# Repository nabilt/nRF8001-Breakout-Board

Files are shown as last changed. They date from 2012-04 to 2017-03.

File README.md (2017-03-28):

nRF8001-Breakout-Board
==========================================

* Author:    Nabil Tewolde (<nabil.tewolde@gmail.com>)
* Version:   0.9
* Website:   <http://www.nabiltewolde.com>
* GitHub:    <https://github.com/nabilt/nRF8001-Breakout-Board>

This hardware project is the reference schematic for the [nRF8001] Bluetooth Low Energy chip redone in Eagle. It is currently untested. The goal of this project is to develop a low power, cheap, cross-platform wireless module for wireless projects. I plan to include open firmware and demos for iOS and Android. Checkout my [blog post] for more info.

[nRF8001]: http://www.nordicsemi.com/eng/Products/Bluetooth-R-low-energy/nRF8001
[blog post]: https://nabil.me/2012/04/09/open-source-bluetooth-4-breakout-board-means-no-more-mi-fi/
Why nRF8001 and not another [Bluetooth 4 chip]?

* Publicly available datasheet
* Simple circuitry, few passives and no integrated uC
* Cheap, $4.98 CAD on [Mouser]
* Small, currently the board is 1’’ x 0.9’’

[Bluetooth 4 chip]: http://developer.bluetooth.org/DevelopmentResources/DevelopmentPlatforms/Pages/Development-Platforms.aspx
[Mouser]: http://ca.mouser.com/ProductDetail/Nordic-Semiconductor/nRF8001-R2Q32-T/?qs=yd0qOhnSiDfAxQAlSXMVEQ%3d%3d

Interesting Bluetooth 4 facts:

* Runs for years on a coin cell battery
* Works over a wide range; 10 to 100 meters
* 1Mbps over the air data rate; 0.2 Mbps throughput 
* Virtually all new devices made in 2012 will contain Bluetooth 4 
* Apple only provides a free API for Bluetooth 4 accessories

Checkout <http://www.bluetooth.com/Pages/Bluetooth-Smart-Devices.aspx> for a list of Bluetooth 4 compatible devices.

Licensing
---------

nRF8001-Breakout-Board by Nabil Tewolde is licensed under a Creative Commons Attribution-ShareAlike 3.0 Unported License.

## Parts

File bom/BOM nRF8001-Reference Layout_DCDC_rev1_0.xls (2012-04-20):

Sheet: Mouser BOM - Table 1
nRF8001 core circuitry Bill of Materials
DC/DC converter enabled
Designator | Value | Footprint | Manufacturer Part # | Mouser Part # | Mouser Price | Quantity | Item Total | Comment
C1, C2 | 18pF | 0603 | VJ0603A100GXACW1BC | 77-VJ0603A100GXACBC | 0.098 | 5 | 0.49 | NP0 +/- 2%
C13, C14 | 9pF | 0603 | GRM1885C1H9R0BZ01D | 81-GRM1885C1H9R0BZ01 | 0.098 | 5 | 0.49 | NP0 +/- 2%
C3 | 2.2nF | 0603 | 77-VJ0603A222GXJPBC | VJ0603A222GXJPW1BC | 0.142 | 3 | 0.426 | X7R +/- 10%
C4 | Not mounted | 0603 |  |  |  | 3 | 0
C5 | 1.8pF | 0603 | VJ0603A1R8BXXCW1BC | 77-VJ0603A1R8BXXCBC | 0.087 | 3 | 0.261 | NP0 +/-0.1pF
C6 | 1.2pF | 0603 | VJ0603A1R2BXACW1BC | 77-VJ0603A1R2BXACBC | 0.087 | 3 | 0.261 | NP0 +/-0.1pF
C7, C9 | 1.0µF | 0603 | C1608X7R1C105KT | 810-C1608X7R1C105K | 0.076 | 5 | 0.38 | X7R +/- 10%
C8 | 1.0nF | 0603 | CC0603KRX7R9BB102 | 603-CC603KRX7R9BB102 | 0.098 | 3 | 0.294 | X7R +/- 10%
C10, C12 | 100nF | 0603 | 0603YC104KAT2A | 581-060316C104K | 0.044 | 5 | 0.22 | X7R +/- 10%
C11 | 33nF | 0603 | C0603C333K4RACTM | 80-C0603C333K4RACTM | 0.076 | 3 | 0.228 | X7R +/- 10%
L1 | 8.2nH | 0603 | CI160808-8N2J | 652-CI160808-8N2J | 0.055 | 3 | 0.165 | High frequency chip inductor +/-5%
L2 | 5.6nH | 0603 | 744761056C | 710-744761056C | 0.36 | 3 | 1.08 | High frequency chip inductor +/-5%
L3 | 3.9nH | 0603 | B82496C3399J | 871-B82496C3399J | 0.382 | 3 | 1.146 | High frequency chip inductor +/-5%
L4 | 10µH | 0603 | MLZ1608M100WT | 810-MLZ1608M100W | 0.087 | 3 | 0.261 | Chip inductor, IDC,min = 50mA, +/-20%
L5 | 15nH | 0603 | L0603C15NJRMST | 80-L0603C15NJRMST | 0.131 | 3 | 0.393 | High frequency chip inductor +/-10%
R1 | 22k | 0603 | AC0603FR-0722KL | 603-AC0603FR-0722KL | 0.022 | 3 | 0.066 | +/-1%
U1 | nRF8001 | QFN32 | nRF8001-R2Q32-T | 949-NRF8001-R2Q32-T | 4.98 | 2 | 9.96 | QFN32 5x5 mm package
X1 | U1 | 3.2 x 2.5 mm | ABM8G-16.000MHZ-B4Y-T | 815-ABM8G-16-B4Y-T | 1.27 | 2 | 2.54 | SMD-3225, 16 MHz, CL=18pF, +/-30 ppm
X2 | 32.768kHz | 3.2 x 1.5 mm | ABS10-32.768KHZ-9-T | 815-ABS10-32.768K9T | 1.08 | 2 | 2.16 | 32.768kHz, Cl=9pF, ±20ppm
 | 2.4GHz |  | A24-HASM-450 | 888-A24-HASM-450 | 6.55 | 1 | 6.55 | Antenna
 |  |  |  |  |  |  | 0
Total |  |  |  |  | 9.173 |  | 27.371
Other Components
Designator | Value | Footprint | Manufacturer Part # |  | Price | Quantity | Item Total | Comment
PCB substrate | FR4 laminate | 18.4 x 16.7 mm |  |  | 1 | 10 | 10 | 2 layer, thickness 1.6 mm, from SeeedStudio
RP SMA |  |  |  |  | 1.95 | 2 | 3.9 | Sparkfun RP SMA
Total |  |  |  |  | 2.95 |  | 13.9
GRAND TOTAL | 41.271

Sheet: Mouser BOM Import - Table 1
C1, C2 | 77-VJ0603A100GXACBC | 10
C13, C14 | 81-GRM1885C1H9R0BZ01 | 10
C3 | VJ0603A222GXJPW1BC | 5
C4 |  | 5
C5 | 77-VJ0603A1R8BXXCBC | 5
C6 | 77-VJ0603A1R2BXACBC | 5
C7, C9 | 810-C1608X7R1C105K | 10
C8 | 603-CC603KRX7R9BB102 | 5
C10, C12 | 581-060316C104K | 10
C11 | 80-C0603C333K4RACTM | 5
L1 | 652-CI160808-8N2J | 5
L2 | 710-744761056C | 5
L3 | 871-B82496C3399J | 5
L4 | 810-MLZ1608M100W | 5
L5 | 80-L0603C15NJRMST | 5
R1 | 603-AC0603FR-0722KL | 5
U1 | 949-NRF8001-R2Q32-T | 2
X1 | 815-ABM8G-16-B4Y-T | 2
X2 | 815-ABS10-32.768K9T | 2

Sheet: Newark BOM - Table 1
nRF8001 core circuitry Bill of Materials
DC/DC converter enabled
Designator | Value | Footprint | Manufacturer Part # | Newark Part # | Newark Price | Comment
C1, C2 | 18pF | 0603 | VJ0603A100GXACW1BC |  |  | NP0 +/- 2%
C13, C14 | 9pF | 0603 | GRM1885C1H9R0BZ01D |  |  | NP0 +/- 2%
C3 | 2.2nF | 0603 | 77-VJ0603A222GXJPBC (http://ca.mouser.com/ProductDetail/Vishay-Vitramon/VJ0603A222GXJPW1BC/) |  |  | X7R +/- 10%
C4 | Not mounted | 0603
C5 | 1.8pF | 0603 | VJ0603A1R8BXXCW1BC |  |  | NP0 +/-0.1pF
C6 | 1.2pF | 0603 | VJ0603A1R2BXACW1BC |  |  | NP0 +/-0.1pF
C7, C9 | 1.0µF | 0603 | C1608X7R1C105KT |  |  | X7R +/- 10%
C8 | 1.0nF | 0603 | CC0603KRX7R9BB102 |  |  | X7R +/- 10%
C10, C12 | 100nF | 0603 | 0603YC104KAT2A |  |  | X7R +/- 10%
C11 | 33nF | 0603 | C0603C333K4RACTM |  |  | X7R +/- 10%
L1 | 8.2nH | 0603 | CI160808-8N2J |  |  | High frequency chip inductor +/-5%
L2 | 5.6nH | 0603 | 744761056C |  |  | High frequency chip inductor +/-5%
L3 | 3.9nH | 0603 | B82496C3399J |  |  | High frequency chip inductor +/-5%
L4 | 10µH | 0603 | MLZ1608M100WT |  |  | Chip inductor, IDC,min = 50mA, +/-20%
L5 | 15nH | 0603 | L0603C15NJRMST |  |  | High frequency chip inductor +/-10%
R1 | 22k | 0603 | AC0603FR-0722KL |  |  | +/-1%
 | nRF8001 | QFN32 | nRF8001-R2Q32-T |  |  | QFN32 5x5 mm package
X1 | U1 | 3.2 x 2.5 mm | ABM8G-16.000MHZ-B4Y-T |  |  | SMD-3225, 16 MHz, CL=18pF, +/-30 ppm
X2 | 32.768kHz | 3.2 x 1.5 mm | ABS10-32.768KHZ-9-T |  |  | 32.768kHz, Cl=9pF, ±20ppm
PCB substrate | FR4 laminate | 18.4 x 16.7 mm |  |  |  | 2 layer, thickness 1.6 mm
Total

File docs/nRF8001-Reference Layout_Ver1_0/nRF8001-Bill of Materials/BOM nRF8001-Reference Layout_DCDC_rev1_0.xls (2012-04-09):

Date: 2010-12-20
nRF8001 core circuitry Bill of Materials
DC/DC converter enabled
Designator | Value | Footprint | Comment
C1, C2, C13, C14 | 15pF | 0402 | NP0 +/- 2%
C3 | 2.2nF | 0402 | X7R +/- 10%
C4 | Not mounted | 0402
C5 | 1.8pF | 0402 | NP0 +/-0.1pF
C6 | 1.2pF | 0402 | NP0 +/-0.1pF
C7, C9 | 1.0µF | 0603 | X7R +/- 10%
C8 | 1.0nF | 0402 | X7R +/- 10%
C10, C12 | 100nF | 0402 | X7R +/- 10%
C11 | 33nF | 0402 | X7R +/- 10%
L1 | 8.2nH | 0402 | High frequency chip inductor +/-5%
L2 | 5.6nH | 0402 | High frequency chip inductor +/-5%
L3 | 3.9nH | 0402 | High frequency chip inductor +/-5%
L4 | 10µH | 0603 | Chip inductor, IDC,min = 50mA, +/-20%
L5 | 15nH | 0402 | High frequency chip inductor +/-10%
R1 | 22k | 0402 | +/-1%
U1 | nRF8001 | QFN32 | QFN32 5x5 mm package
X1 | 16MHz | 3.2 x 2.5 mm | SMD-3225, 16 MHz, CL=9pF, +/-50 ppm
X2 | 32.768kHz | 3.2 x 1.5 mm | SMD-3215, 32.768kHz, Cl=9pF, ±20ppm
PCB substrate | FR4 laminate | 18.4 x 16.7 mm | 2 layer, thickness 1.6 mm

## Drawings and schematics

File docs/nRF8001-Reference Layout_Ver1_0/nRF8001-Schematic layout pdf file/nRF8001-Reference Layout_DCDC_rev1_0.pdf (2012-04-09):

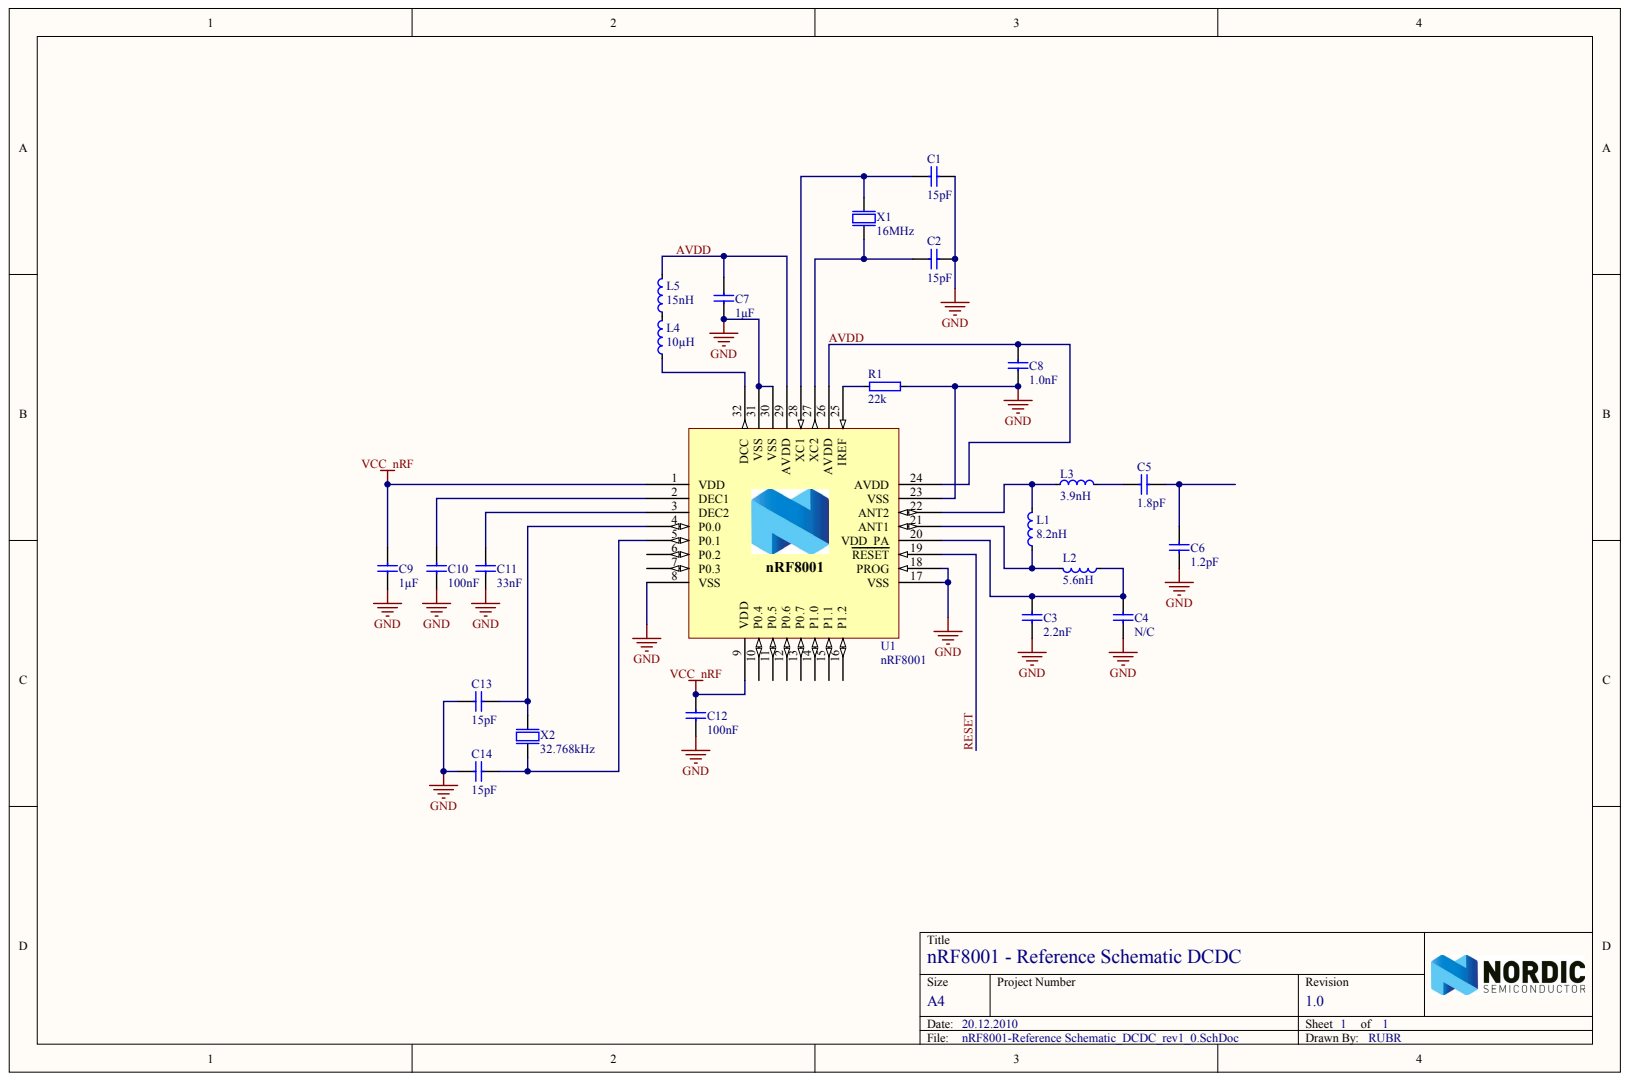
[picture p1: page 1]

Title Size nRF8001 - Reference Sche matic DCDC

A 4 | Project Number | Re visio n 1.0

Date: File: 20.12.201 0 | Sheet 1 o f 1

nRF8001-Reference Schematic_DCDC_rev 1_0.SchDoc | Drawn By : RUBR

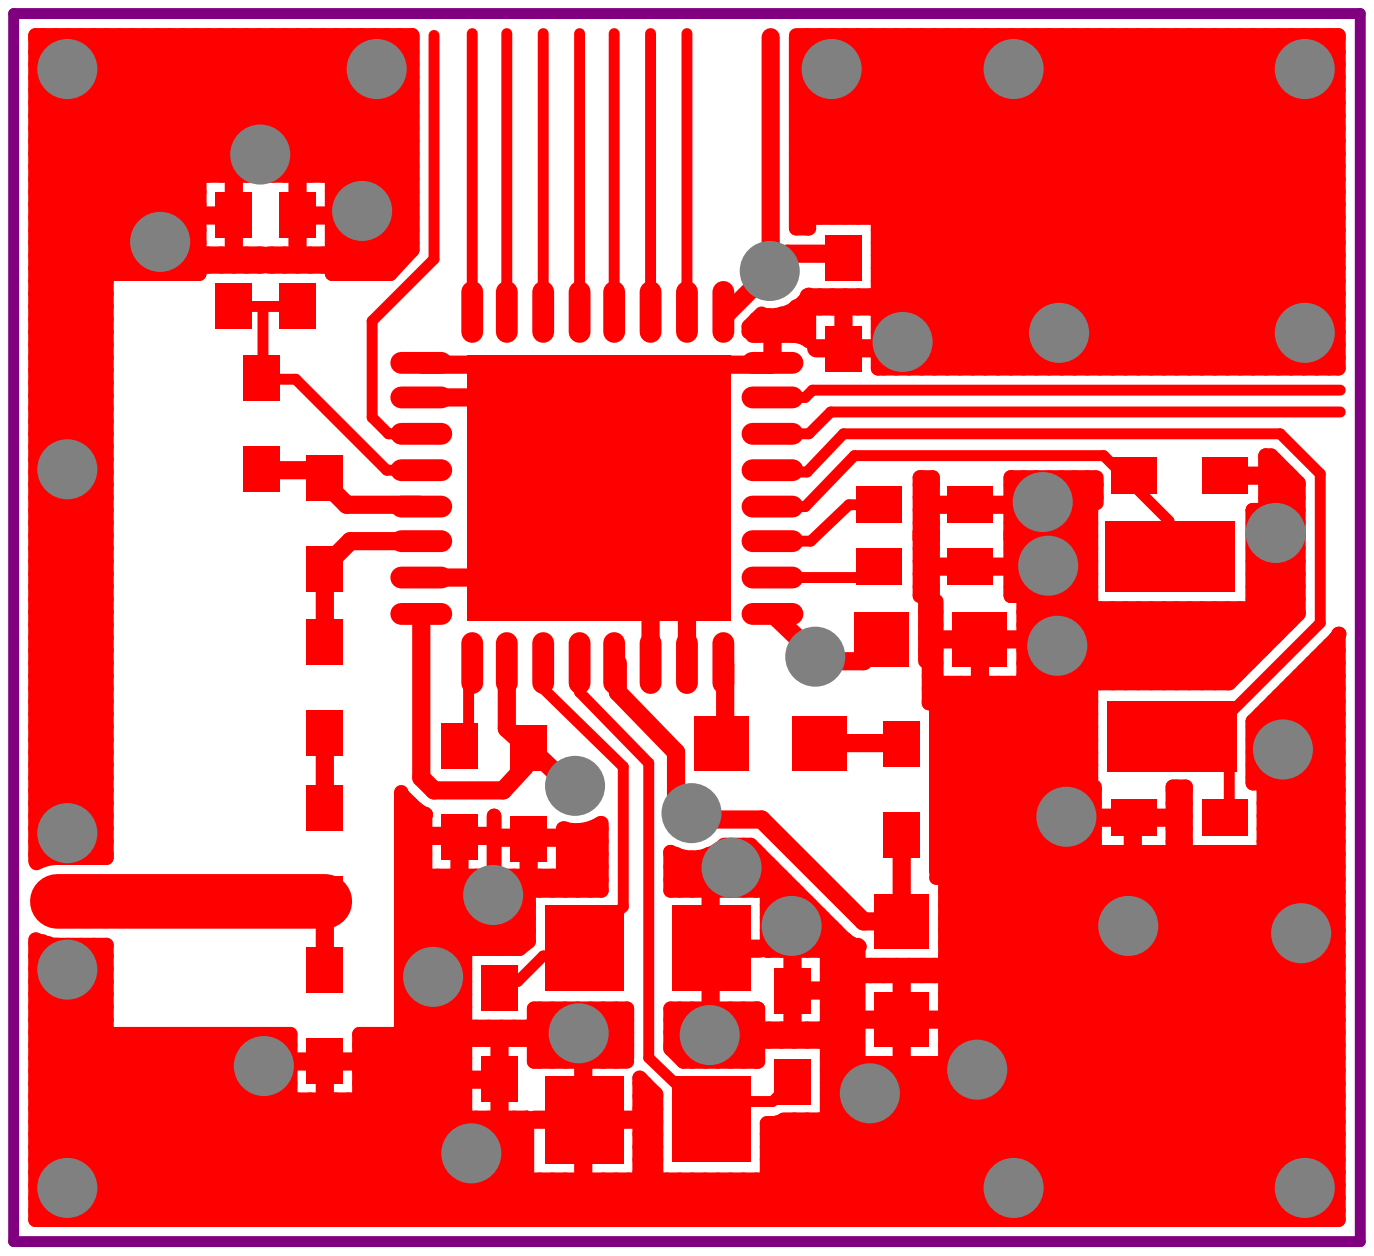
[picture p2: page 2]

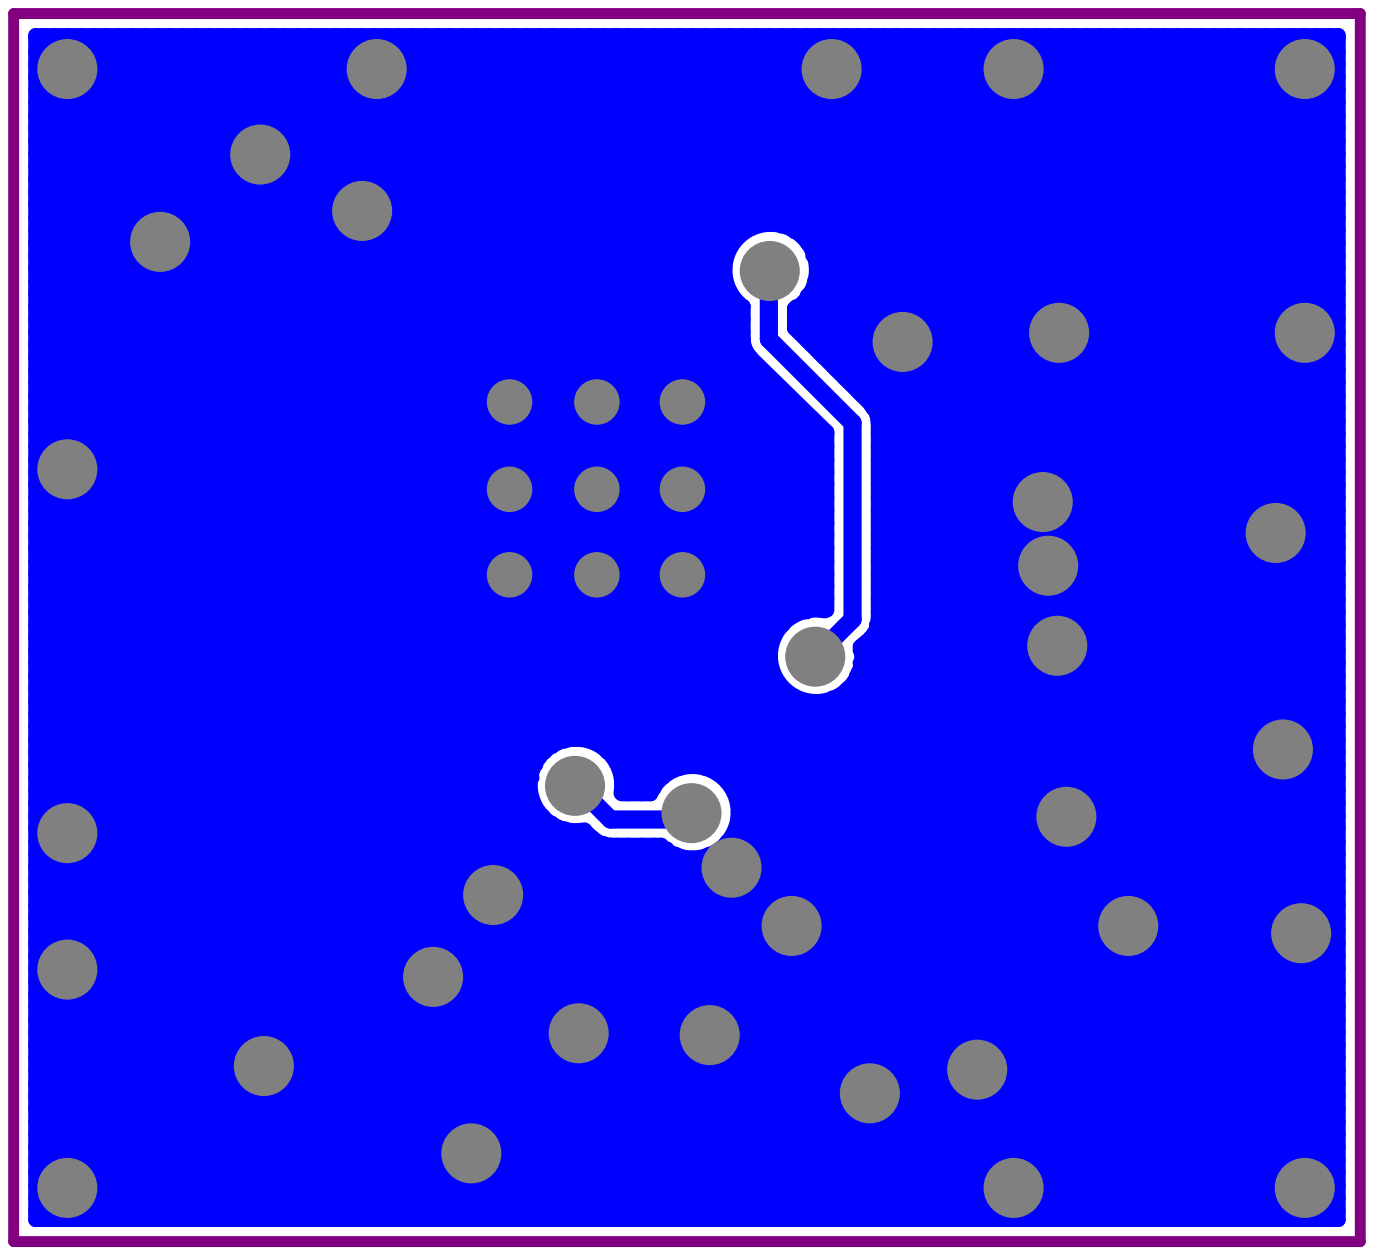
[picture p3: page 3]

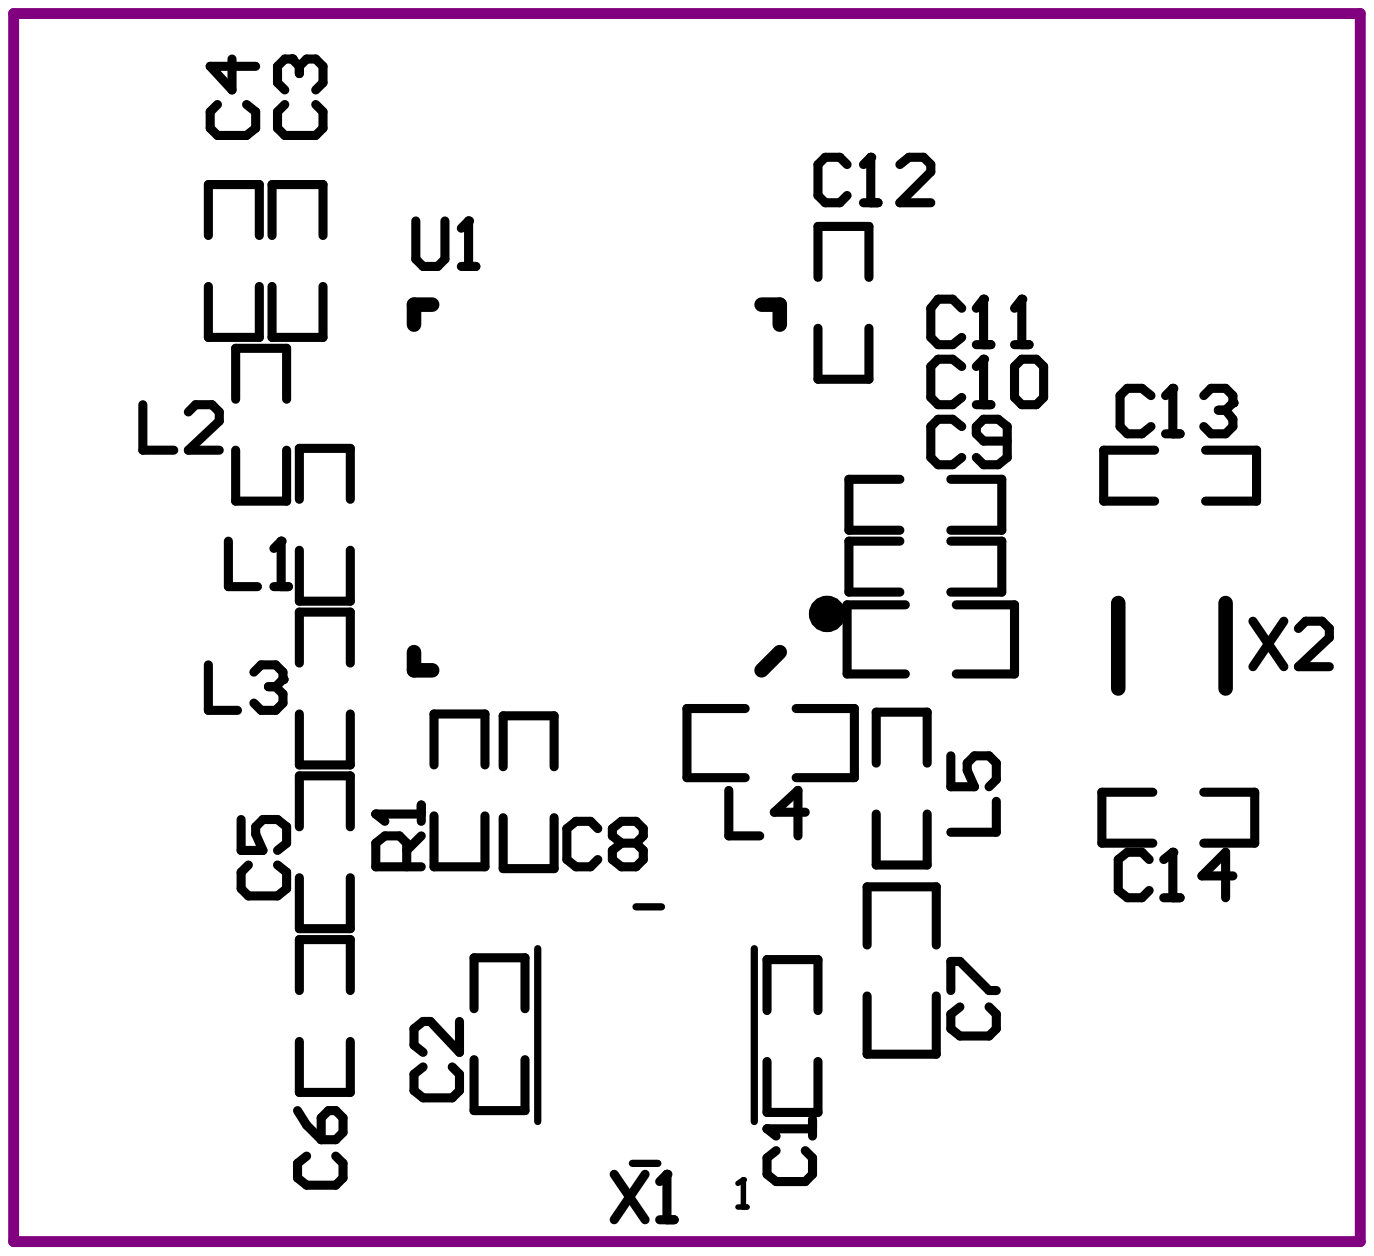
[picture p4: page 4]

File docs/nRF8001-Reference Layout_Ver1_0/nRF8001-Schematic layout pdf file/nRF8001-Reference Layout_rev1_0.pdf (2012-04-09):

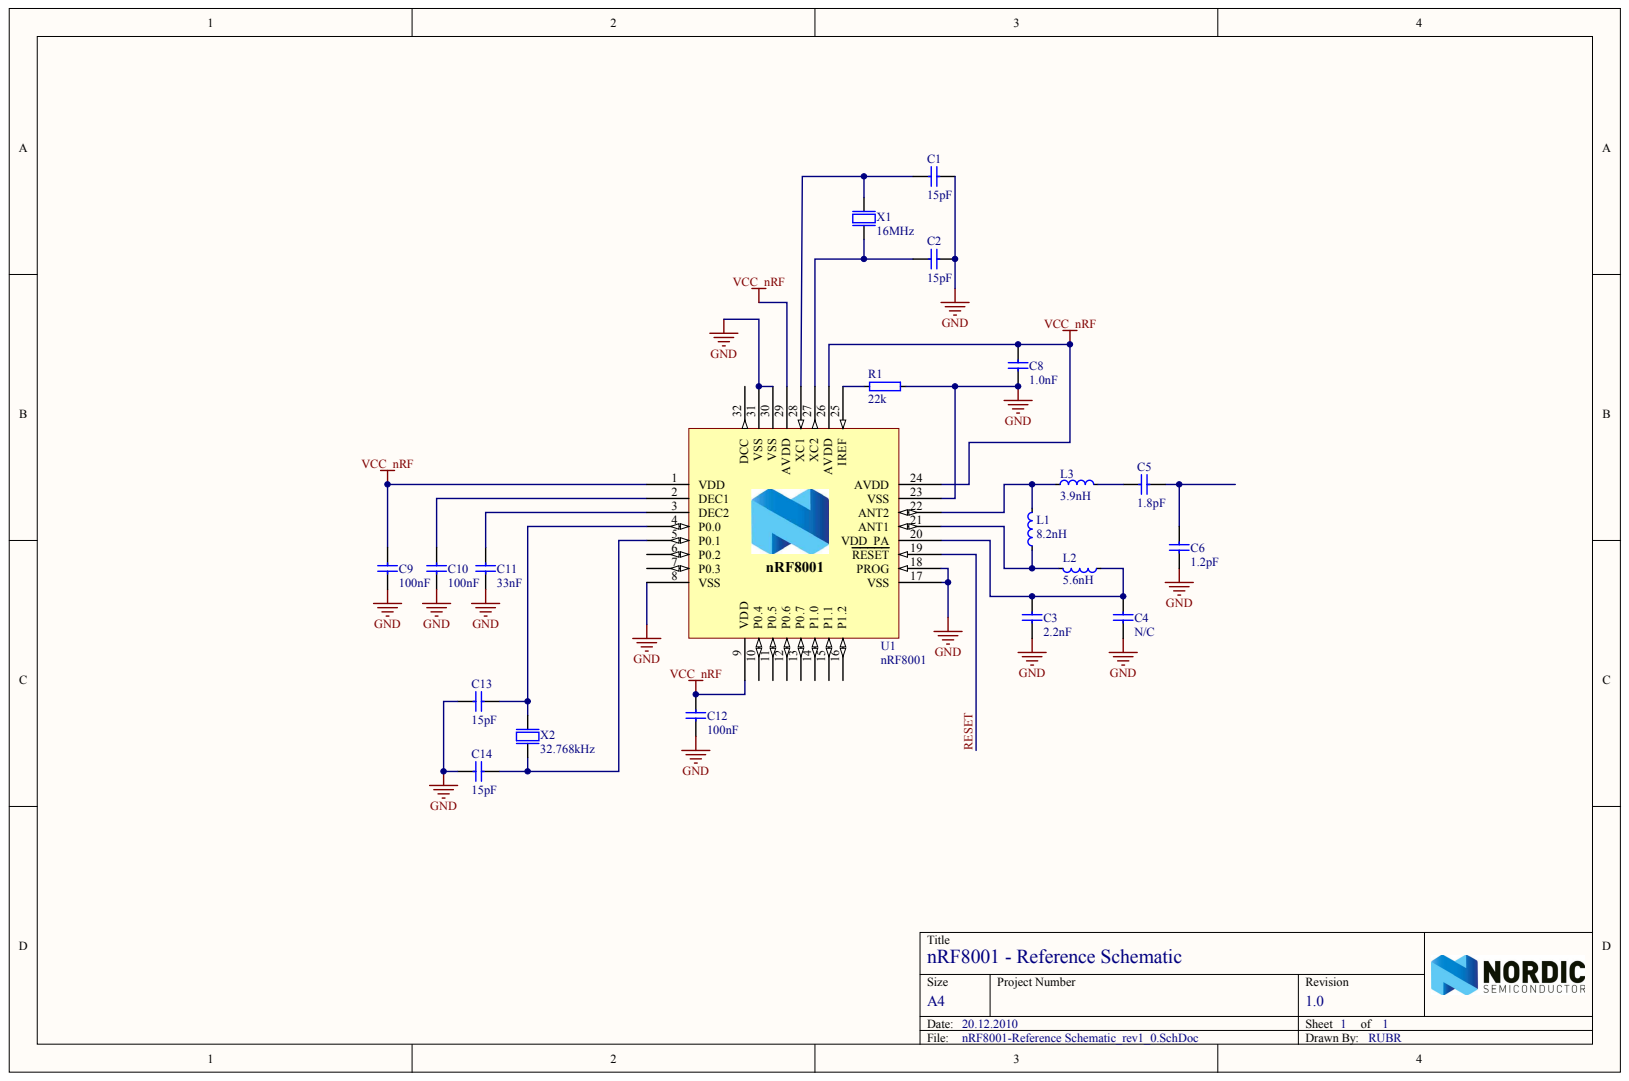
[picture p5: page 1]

Title Size nRF8001 - Reference Sche matic

A 4 | Project Number | Re visio n 1.0

Date: File: 20.12.201 0 | Sheet 1 o f 1

nRF8001-Reference Schematic_rev1_0.S chDoc | Drawn By : RUBR

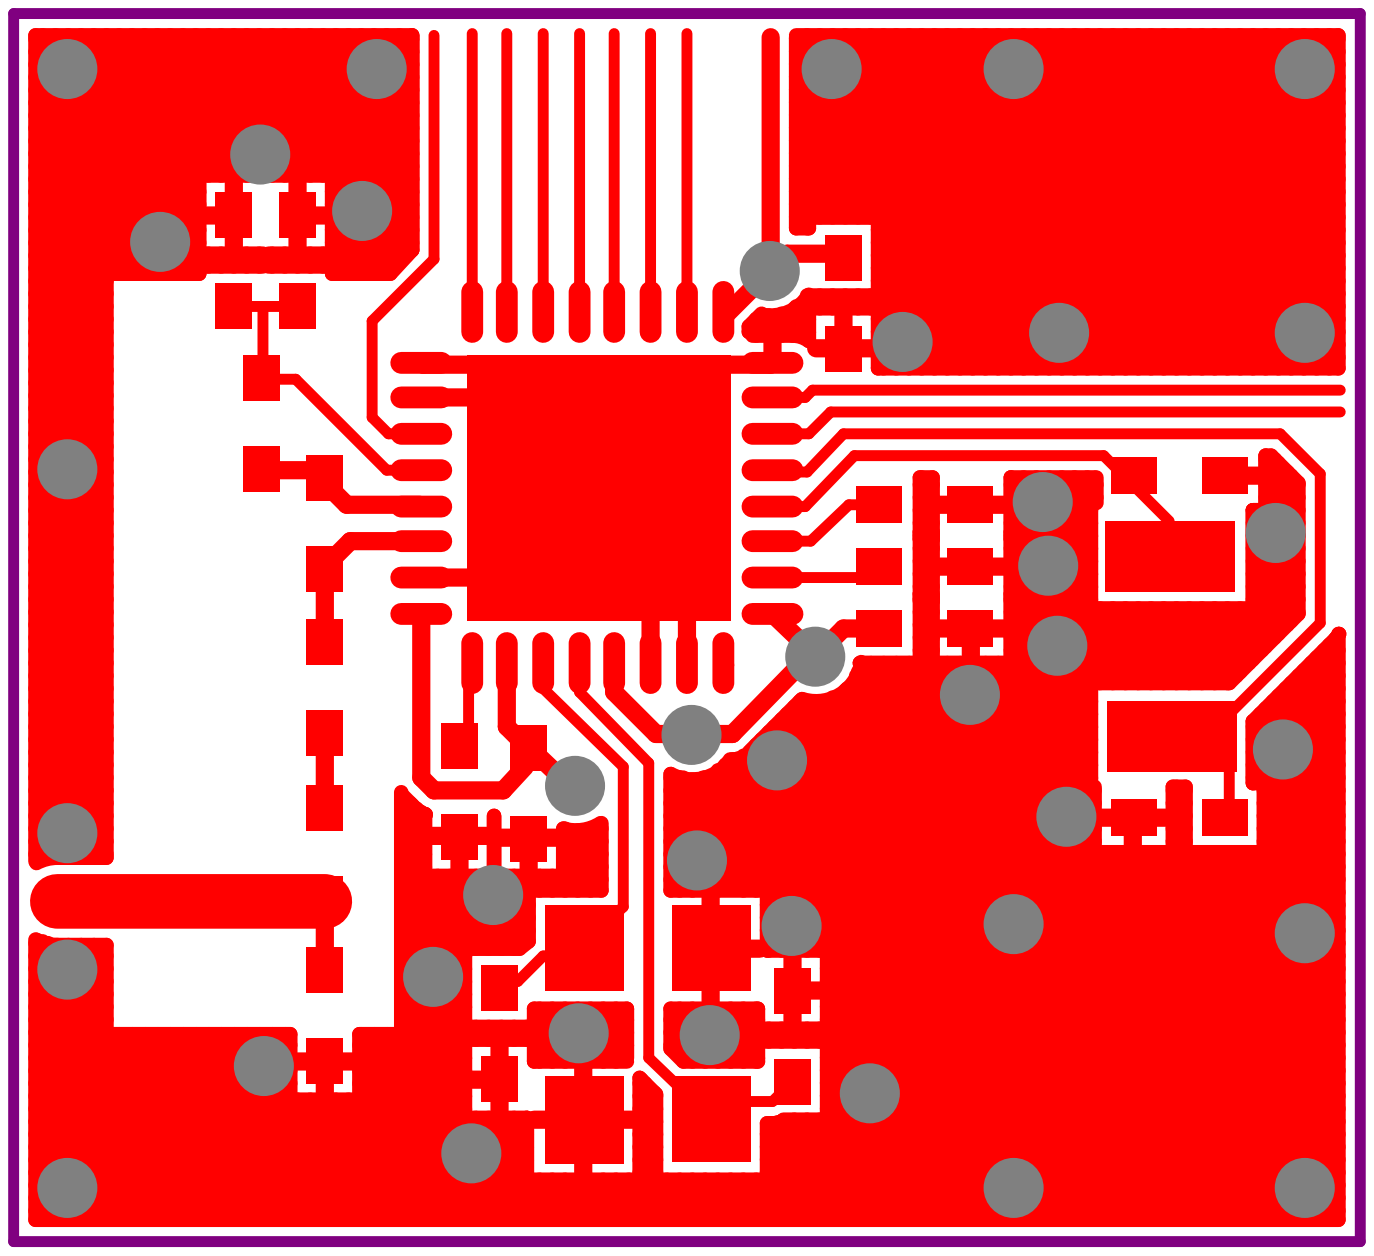
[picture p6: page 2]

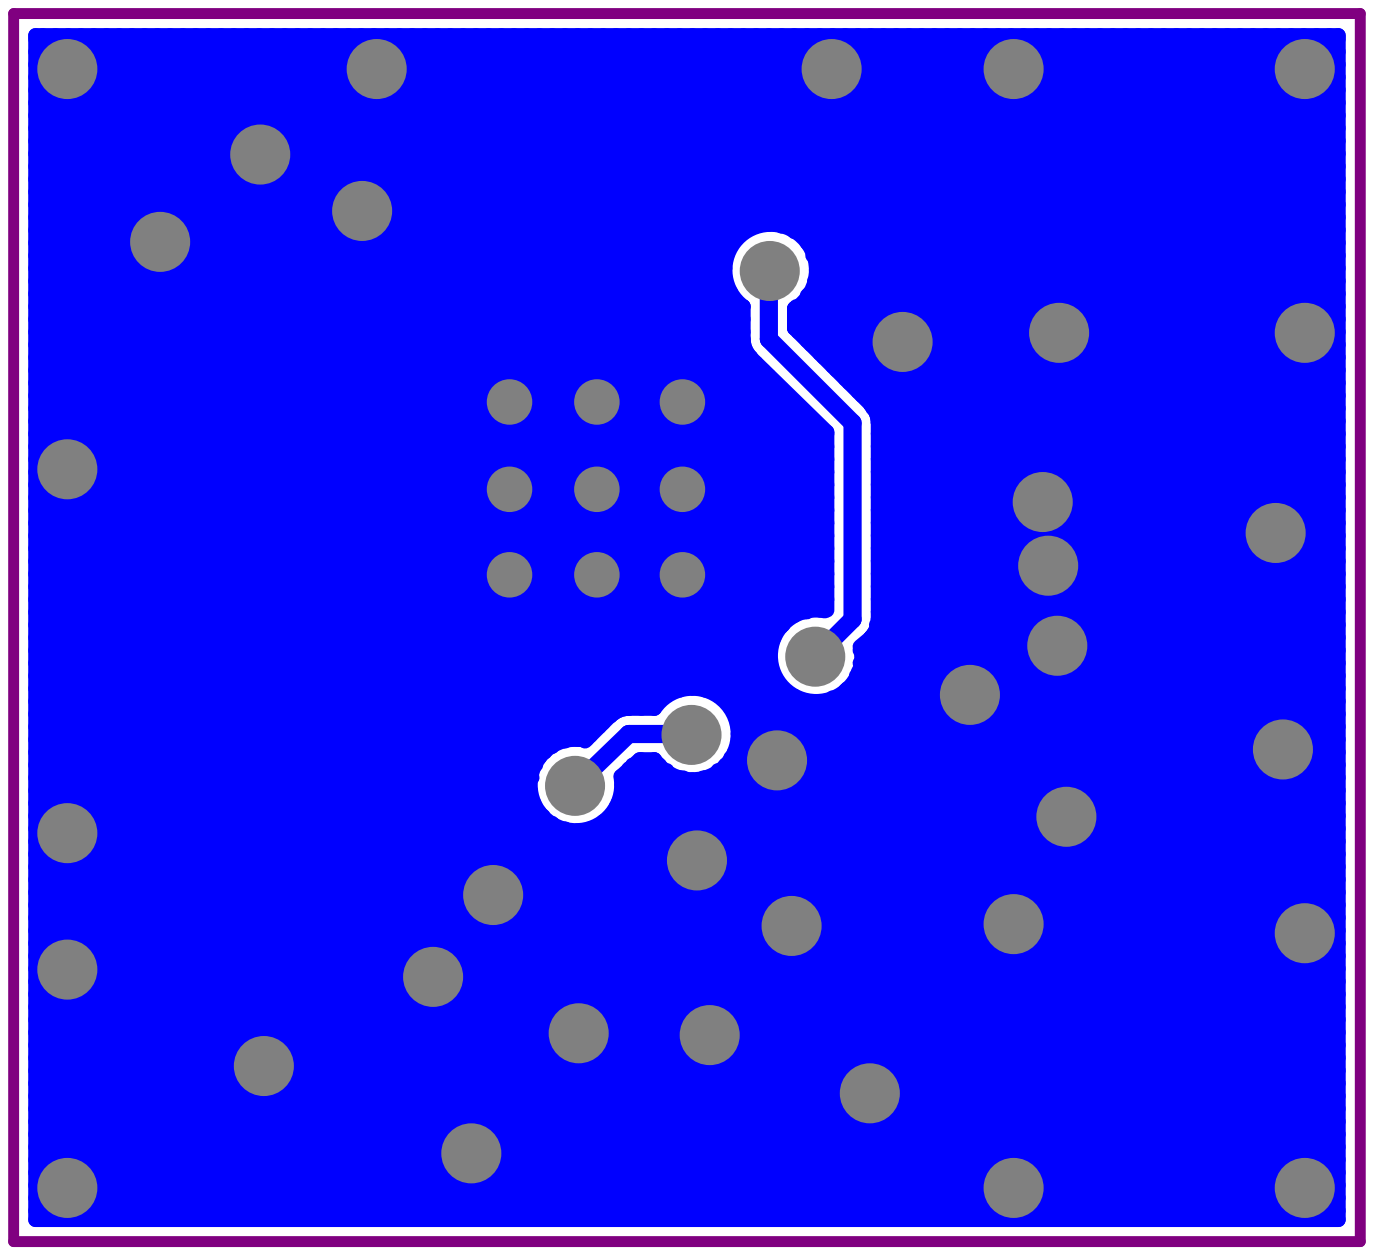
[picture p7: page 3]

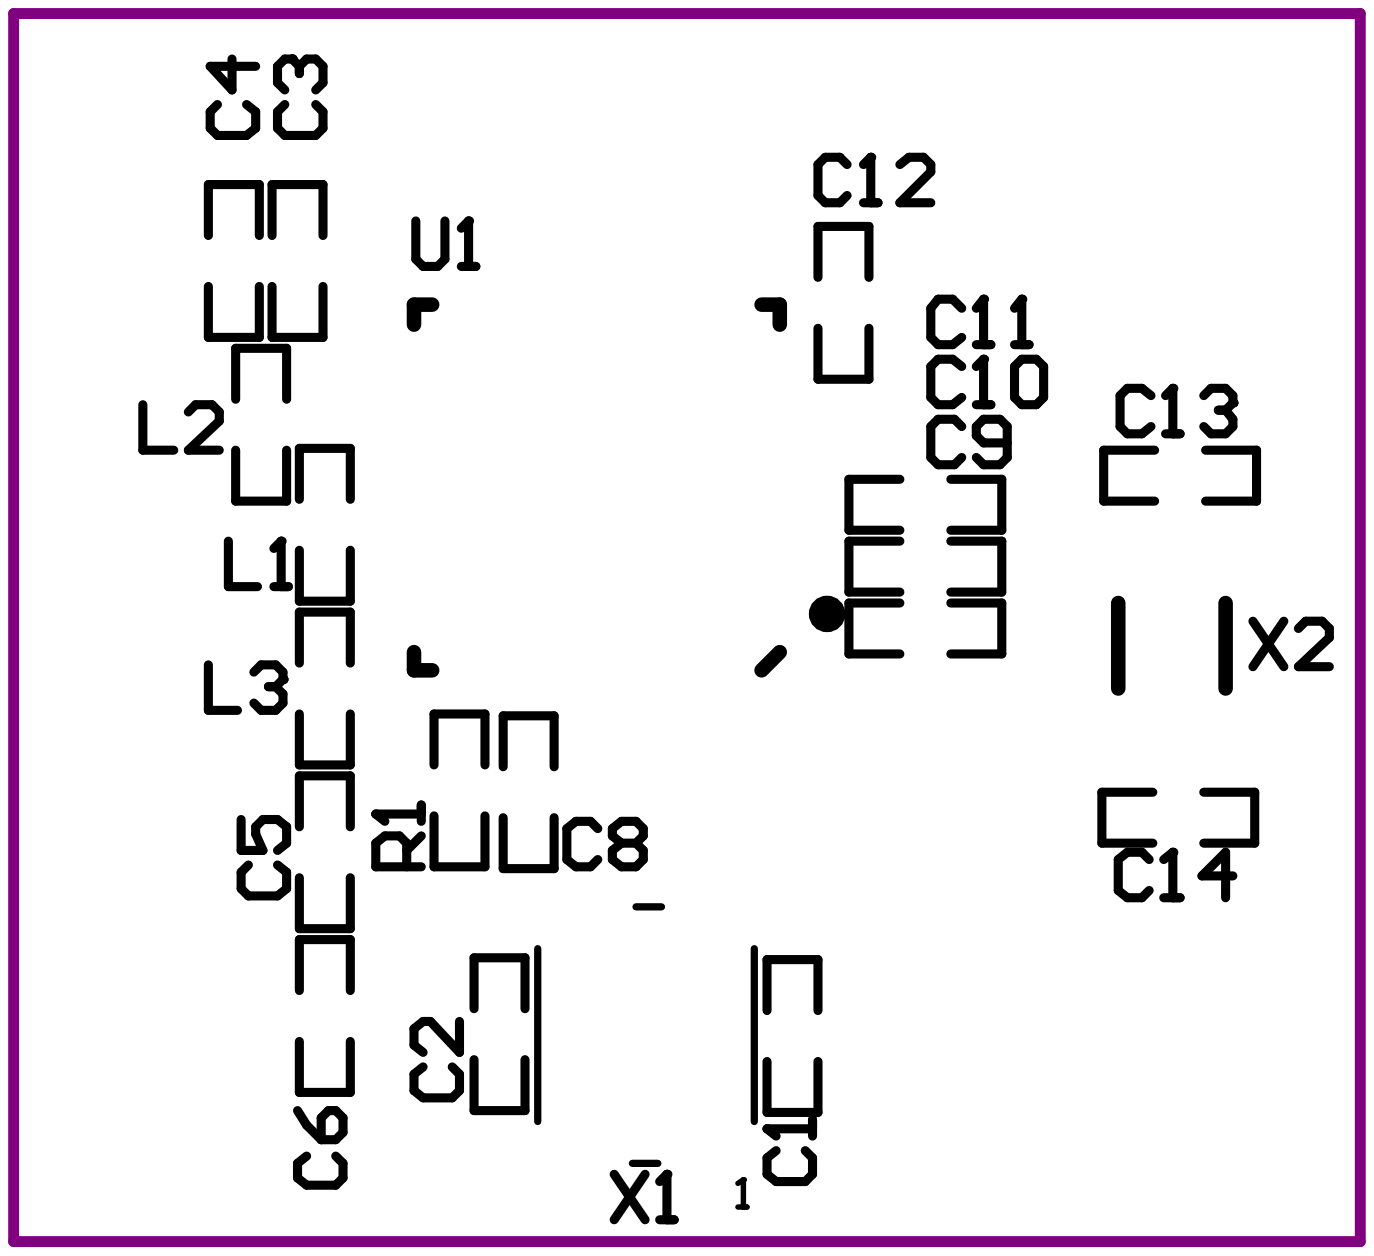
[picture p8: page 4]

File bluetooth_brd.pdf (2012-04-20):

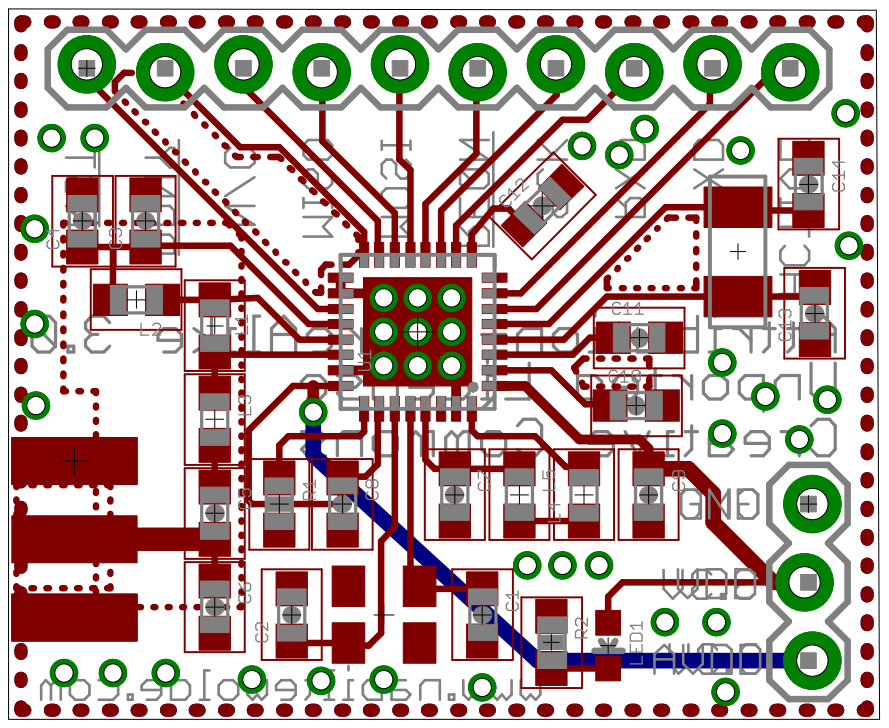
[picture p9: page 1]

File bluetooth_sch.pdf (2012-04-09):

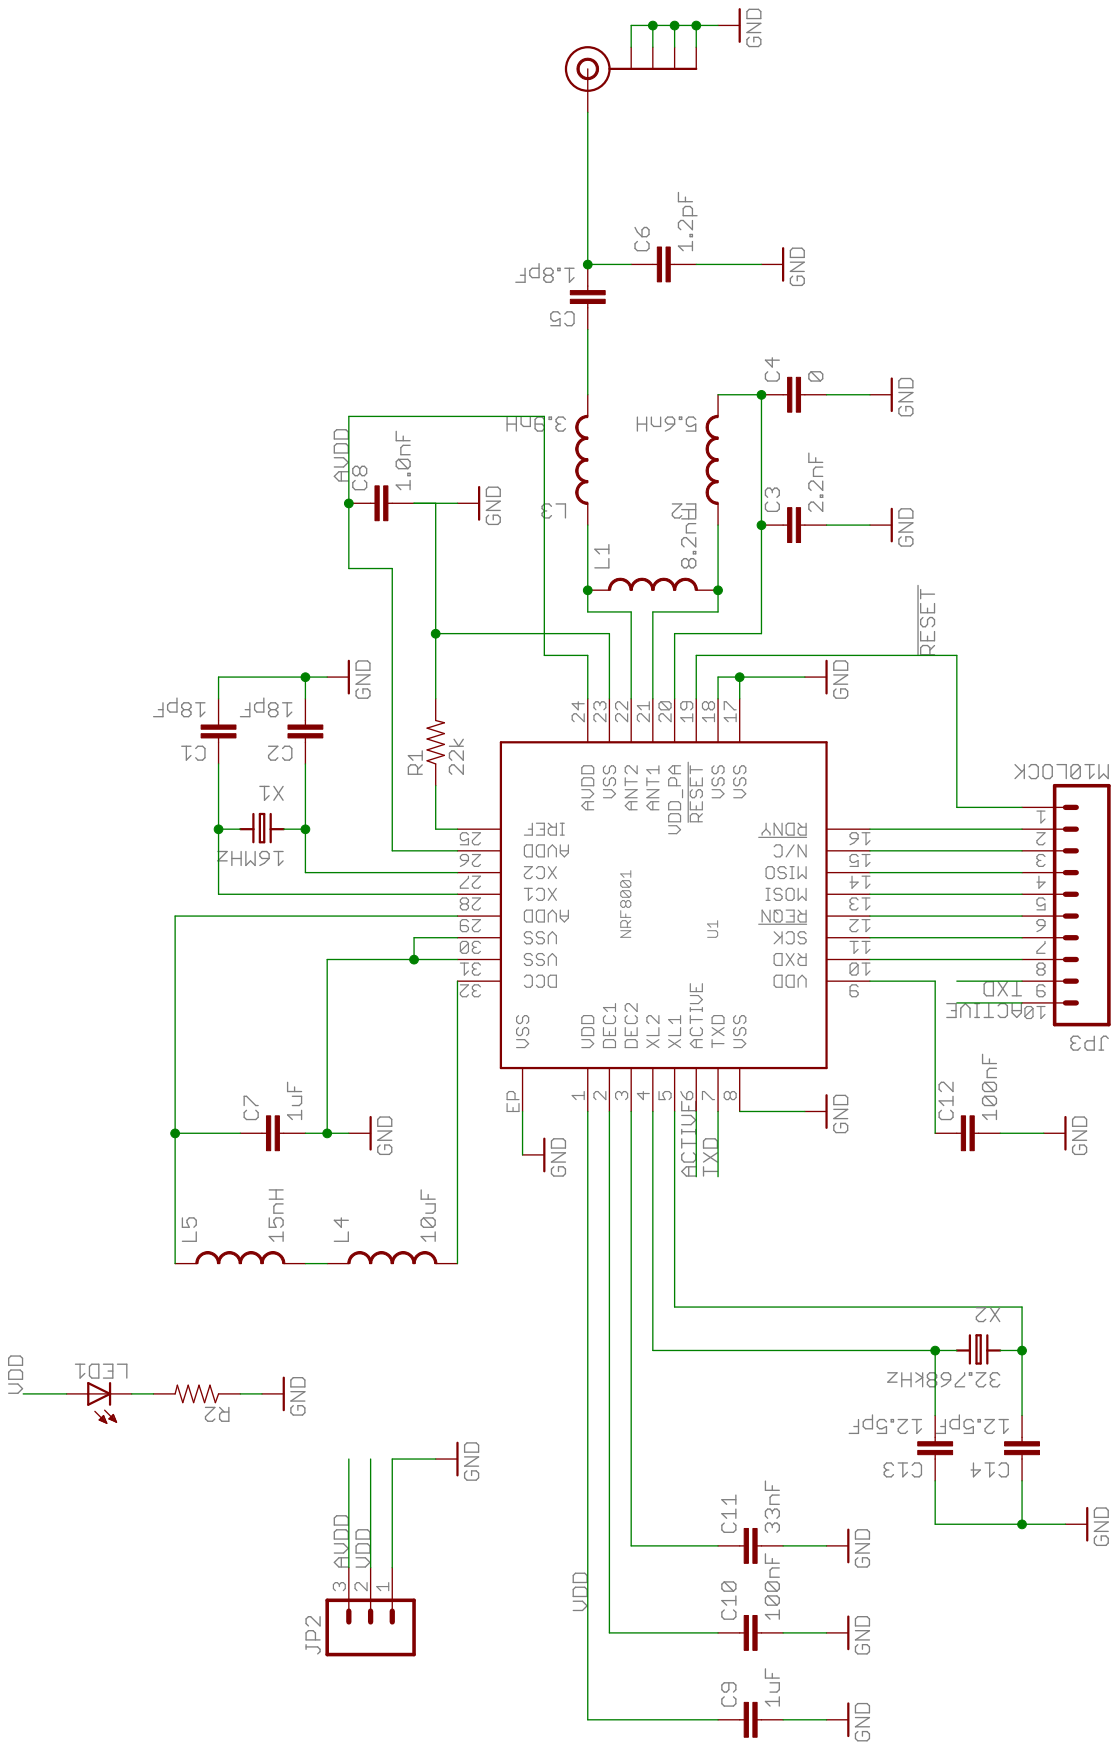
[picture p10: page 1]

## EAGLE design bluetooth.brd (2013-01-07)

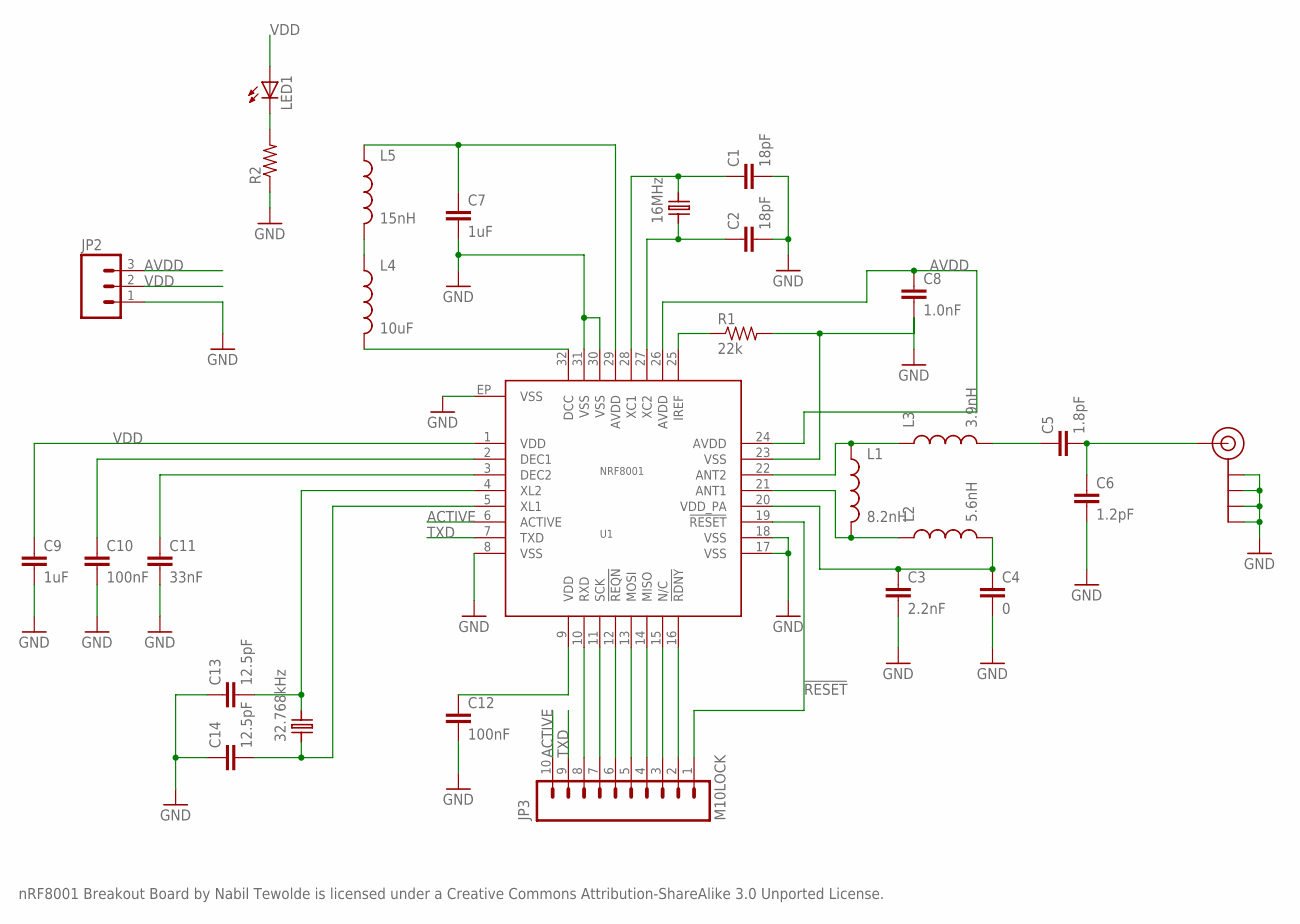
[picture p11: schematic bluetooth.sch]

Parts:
C1, C2: 18pF; 0603-CAP
C3: 2.2nF; 0603-CAP
C4: 0; 0603-CAP
C5: 1.8pF; 0603-CAP
C6: 1.2pF; 0603-CAP
C7, C9: 1uF; 0603-CAP
C8: 1.0nF; 0603-CAP
C10, C12: 100nF; 0603-CAP
C11: 33nF; 0603-CAP
C13, C14: 12.5pF; 0603-CAP
J$1: SMA_EDGE; SMA-EDGE
JP2: M03LOCK; 1X03_LOCK
JP3: M10LOCK; 1X10_LOCK
L1: 8.2nH; 0603
L2: 5.6nH; 0603
L3: 3.9nH; 0603
L4: 10uF; 0603
L5: 15nH; 0603
LED1: LED0603; LED-0603
R1: 22k; 0603-RES
R2: RESISTOR0603-RES; 0603-RES
U1: NRF8001; QFN-32
X1: 16MHz; CRYSTAL-2.5X3.5
X2: 32.768kHz; CRYSTAL-ABS10

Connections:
!RESET: JP3.1, U1.19 (!RESET)
ACTIVE: JP3.10, U1.6 (ACTIVE)
AVDD: C8.1, JP2.3, U1.24 (AVDD), U1.26 (AVDD)
GND: C1.2, C2.2, C3.2, C4.2, C6.2, C7.2, C8.2, C9.2, C10.2, C11.2, C12.2, C13.1, C14.1, J$1.GND@0 (GND), J$1.GND@1 (GND), J$1.GND@2 (GND), J$1.GND@3 (GND), JP2.1, R1.2, R2.1, U1.8 (VSS), U1.17 (VSS), U1.18 (VSS), U1.23 (VSS), U1.30 (VSS), U1.31 (VSS), U1.EP (VSS)
unnamed: L4.1, L5.2
unnamed: L4.2, U1.32 (DCC)
unnamed: L1.1, L3.1, U1.22 (ANT2)
unnamed: C7.1, L5.1, U1.29 (AVDD)
unnamed: LED1.C, R2.2
unnamed: C10.1, U1.2 (DEC1)
unnamed: C11.1, U1.3 (DEC2)
unnamed: L1.2, L2.1, U1.21 (ANT1)
unnamed: C5.1, L3.2
unnamed: C5.2, C6.1, J$1.SIG (SIGNAL)
unnamed: R1.1, U1.25 (IREF)
unnamed: C3.1, C4.1, L2.2, U1.20 (VDD_PA)
unnamed: C2.1, U1.27 (XC2), X1.P$1
unnamed: C1.1, U1.28 (XC1), X1.P$3
unnamed: C13.2, U1.4 (XL2), X2.P$2
unnamed: C14.2, U1.5 (XL1), X2.P$1
unnamed: JP3.2, U1.16 (!RDNY)
unnamed: JP3.3, U1.15 (N/C)
unnamed: JP3.4, U1.14 (MISO)
unnamed: JP3.5, U1.13 (MOSI)
unnamed: JP3.6, U1.12 (!REQN)
unnamed: JP3.7, U1.11 (SCK)
unnamed: JP3.8, U1.10 (RXD)
TXD: JP3.9, U1.7 (TXD)
VDD: C9.1, C12.1, JP2.2, LED1.A, U1.1 (VDD), U1.9 (VDD)

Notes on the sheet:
nRF8001 Breakout Board by Nabil Tewolde is licensed under a Creative Commons Attribution-ShareAlike 3.0 Unported License.

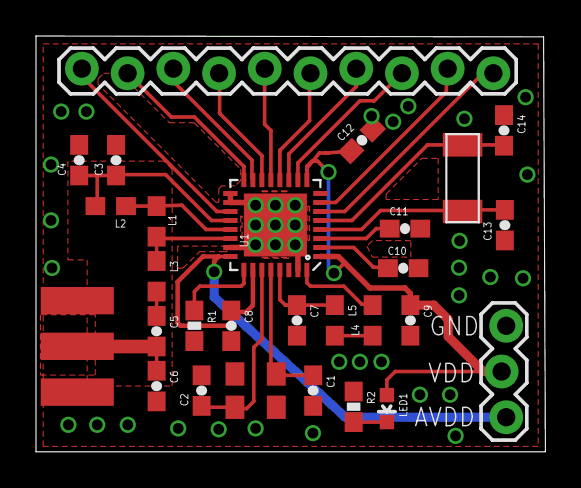
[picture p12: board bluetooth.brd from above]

Board: 2 copper layers, 28.3 x 23.1 mm, 28 parts (0 on the bottom side), 29 nets.

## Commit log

2012-04-09 fix readme
    [BOM nRF8001-Reference Layout_DCDC_rev1_0.xls, bluetooth.brd, bluetooth.sch]
2012-04-20 updated BOM, fixed 32kHz crystal footprint and added datasheet
    [BOM nRF8001-Reference Layout_DCDC_rev1_0.xls, bluetooth.brd, bluetooth.sch]
2012-04-20 small DRC fix, added gerber files
    [bluetooth.brd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]
2013-01-07 Connected pin 9 (power) to VDD. Oops
    [bluetooth.brd, bluetooth.sch]

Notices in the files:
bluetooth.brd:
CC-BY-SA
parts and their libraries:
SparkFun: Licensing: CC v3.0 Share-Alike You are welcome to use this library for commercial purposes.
